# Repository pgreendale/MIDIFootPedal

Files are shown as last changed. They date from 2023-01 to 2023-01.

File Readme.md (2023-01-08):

# MIDI Interface for a organ footpedal
<figure>
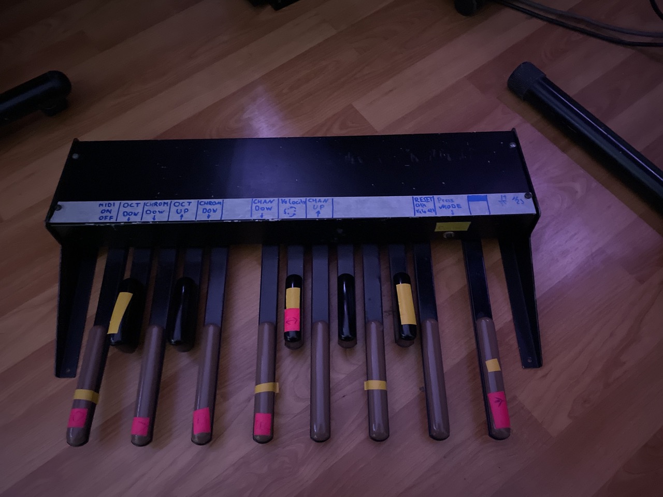
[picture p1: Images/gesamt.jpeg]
Completed pedal
    
    <figcaption>Midified organ pedal.</figcaption>
</figure>
## Intro
This device came from a friend. I assume, its base came from an Vermona ET6-2 organ,
an electronic organ produced in the former GDR. The build is simple, just long hinges with
pull springs and a switch per pedal.

Someone converted it before, but the original interface from unknown origin is dead.

Analysing the circuit revealed switches organized in groups, eight per group, so
multiplexing is possible and there were also diodes installed, which allows polyphonic
muxed readout.

I replaced that interface board with the Arduino nano and kept an eye on using as
few as possible external components (parts shortage, you know?). The AVRs have
useful pullups, so nothing special.

## Features
Polyphonic.
Base Note, Midi Channel and Velocity are configurable.

## Build
<figure>
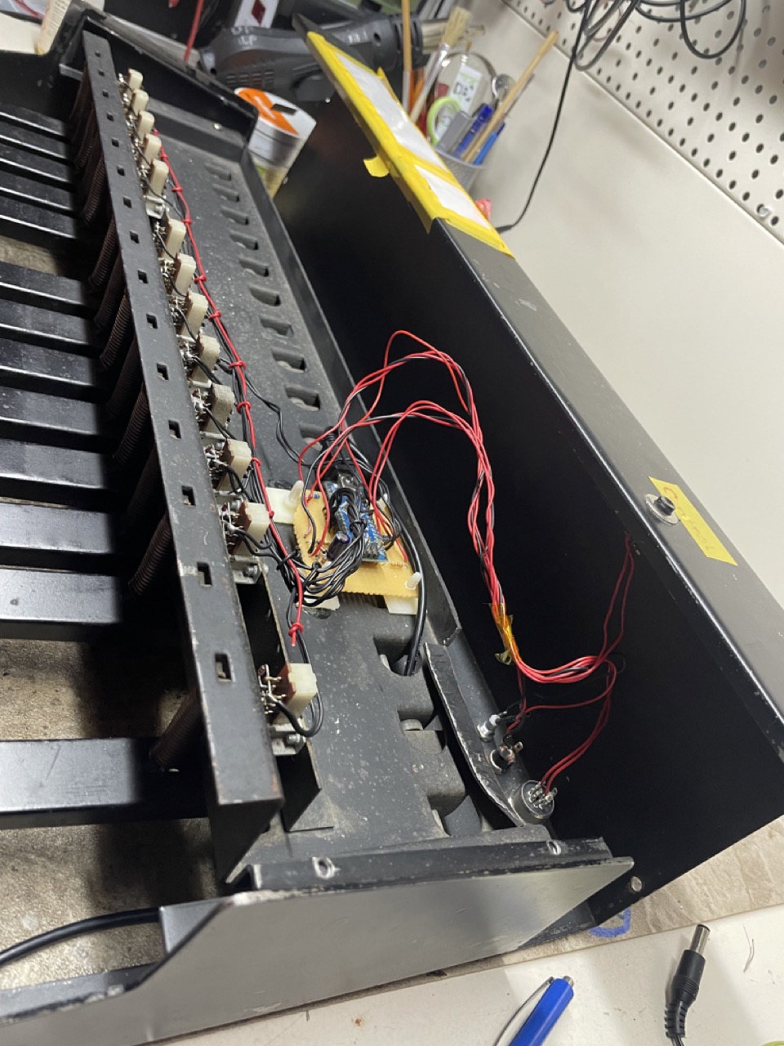
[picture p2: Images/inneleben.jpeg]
Pedals guts, housing removed
    
    <figcaption>A look at the pedals guts reveal the newly installed Arduino and messy wiring</figcaption>
</figure>

### Hardware needed
* Arduino Uno / Nano with Atmega328 
* 2 220k resistors for MIDI
* 5 1k resistors for buttons and LED
* Buttons / momentary switches (! Carbon pad switches may have too much resistance)
Schmatics are [here]().

The build is easy. I put the arduino on perfboard, added the midi resistors and the input filtering/protection, then connected the keys. If you change the design for more
key groups, add a 1k resistor in the added multiplexed lines. This is basic protection
when the MCU in in random condition at powerup.

When build, compile the arduino sketch, upload it and voila! If something doesn't go as expected, you can use the debugging mode for some basic checks.

### Note on powersupplies
For Power regulation, arduino's internal linear regulator is used.
Depending on source, the absolute maximum voltage may be in the 15V ballpark (as
  my arduino clones from [AZ Delivery](https://www.az-delivery.de/products/nano-v3-mit-ch340-arduino-kompatibel) are). If you power those, remember that rectified transformer powersupplies have peaking off-load-voltages which are much higher than the specified RMS (usually by 1.4141 * V_RMS) because of sinusodial RMS to peak values. Since our arduino has low power demands, voltage goes up to nearly off-load.
  I would say, a 9V DC powersupply is safe to use, every kind of switching power supply, Batteries etc.

## Software
The Midi handling is done by the [FourtySevenEffects](https://github.com/FortySevenEffects/arduino_midi_library) library.
It may be a little overkill for sending simple note-on and note-off values, but I liked
the Idea of trying it out, there is a good [Doxygen](https://fortyseveneffects.github.io/arduino_midi_library/) documentation.

The software is customizable, feel free to change PIN numbers for your designs if needed.

There is some pointer magic and some size=sizeof() stuff implemented, to keep the
design expandable, you can add additional key groups by adding pin numers to the
*MUX_PORTS[]* array.

## Debugging
There is a simple debug mode implemented, which is activated if the *mode button* is
held down **during a reset** until the software changes into modeswitch (led is blinking). If you connect a computer via the Arduino USB Interface and open a serial console on the usb serial device with 9600baud transmission rate, you'll see information about the internal eeprom state, which key is pressed, keyboard state
values and if the unit tries to send on or off messages via midi.

Please note that midi operation is not possible in debug mode due to different UART speeds used for midi and debugging.

## Mode button
The mode button allows on-stage configuration of the interface.
On my pedal, it is organized as following:

| Nr. | Key | Function |
|-----|---|---|
| 1 | C_0 | Midi on/off (not implemented) |
| 2 | **C#_0** | Shift Keys 1 Octave down |
| 3 | D_0 | Shift Keys 1 Semitone down |
| 4 | **D#_0** | Shift Keys 1 Octave up |
| 5 | E_0 | Shift Keys 1 Semitone up |
| 6 | F_0 | Change MIDI channel DOWN |
| 7 | **F#_0** | Cycle Velocity by + 1/4 range |
| 8 | G_0 | Change MIDI channel UP |
| 12  | B_0 | **RESET** settings to default |
| 13  | C_1 | Send Midi Panic CC120 on Chan |

To activate the options, press the mode button, the LED changes from static
to blinking, then press the key corresponding to your intended change. The
changes are immediately applied and stored in memory, so everything will
be kept for the net gig. The new midi channel is displayed when changed.

If you have pressed mode by accident, just wait until the LED stops blinking, about 10
seconds.  

Key Functions can be changed, rearranged or removed in Source Code. The Key numbers are absolute, so Key 9 means the first key in the second group.

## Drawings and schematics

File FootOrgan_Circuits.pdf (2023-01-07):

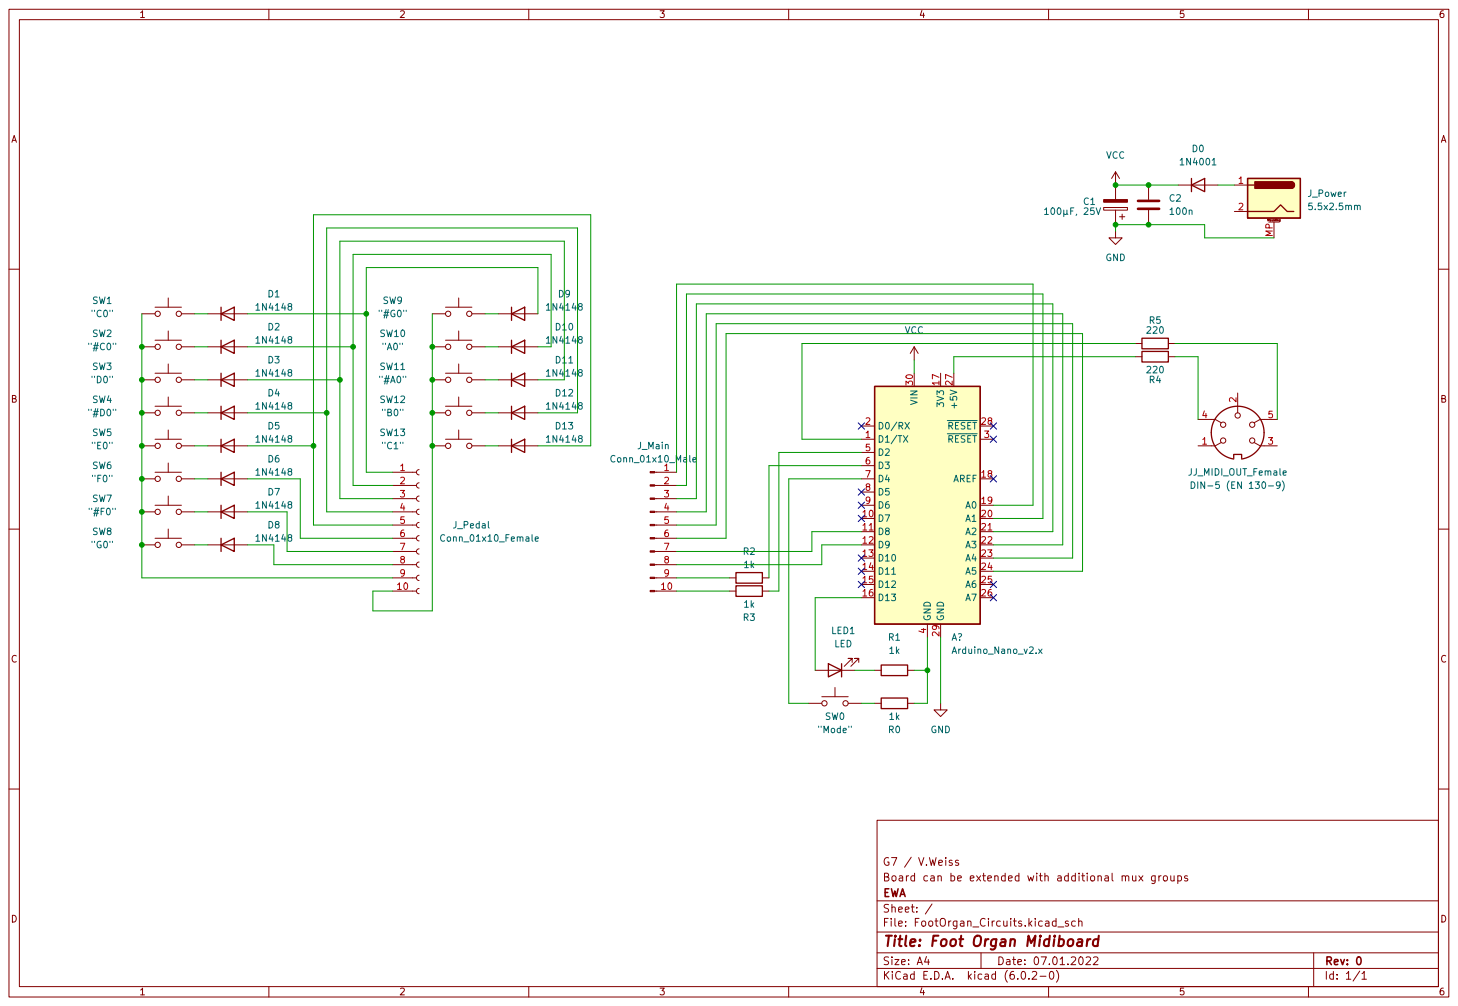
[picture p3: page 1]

Board can be extended with additional mux groups G7 / V.Weiss

Id: 1/1 Title: Foot Organ Midiboard

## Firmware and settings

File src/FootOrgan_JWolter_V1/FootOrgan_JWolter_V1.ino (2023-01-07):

#include <MIDI.h>
#include <EEPROM.h>

int ledPin = 13; 
int modePin = 4;
/* input Switch Configurations */
int SW_KEY[]{
  14,15,16,17,18,19,8,9
};
int SW_LEN = sizeof(SW_KEY)/sizeof(SW_KEY[0]);

/*Pins for muxing inputs*/
int MUX_PORTS[]{
  2,3
};

/*
  Key state variable, 0 = no key pressed , assuming n_mux 
  muxed switch groups with 8 bit port width and 
*/
byte KEY_STATE[sizeof(MUX_PORTS)/sizeof(MUX_PORTS[0])]{0};

struct Config{
  byte velocity; 
  byte note_offset; 
  byte channel;
  bool midi_on;
  byte debug;
};
//configuration struct 
Config conf;

//set true if generic debugging is wanted 
bool debug_mode = false ;

/*mode number definitions MODE_ALIAS Key Number*/
#define MIDI_ON_OFF 1 
#define OCT_UP 4
#define OCT_DOWN 2
#define CHROM_UP 5
#define CHROM_DOWN 3
#define CHAN_UP 8
#define CHAN_DOWN 6
#define VELOCITY 7 
#define RESET_DEFAULT 12 
#define PANIC 13
//timeout cycle in menue, maximum in 100ms steps 
#define TIMEOUT_MAX 100 

MIDI_CREATE_DEFAULT_INSTANCE();

/*
  reads keyboard and returns count of first key found (usually lowest)
*/
void debug(void);
void read_keys(int mux[], byte state[]);


int read_key_single(void){
  read_keys(MUX_PORTS, KEY_STATE); //update keys
  int temp = 0;
  for(int group_idx = 0; group_idx < sizeof(KEY_STATE)/sizeof(KEY_STATE[0]) ; group_idx++ ){ 
    byte mask = 0x01; 
    for(int key_idx = 1; key_idx <= 8 ; key_idx++){
      if((mask & KEY_STATE[group_idx]) != 0) {
          return(group_idx * 8 + key_idx);
        }
        mask = mask << 1 ; 
      }
    }
  return 0;
}
/* Changes configuration by pressing a key according to its second function*/
void modeswitch(){
  int choice  = 0;
  if (debug_mode){
        debug();
  }
  while(digitalRead(modePin)==LOW){
    int timeout = 0; 
    while( (choice==0) && (timeout < TIMEOUT_MAX) ){
      choice = read_key_single();
      if(debug_mode){
        Serial.print("Mode:");Serial.println(choice); 
      }
      digitalWrite(ledPin, HIGH);
      delay(50);
      digitalWrite(ledPin, LOW); 
      delay(50);
      timeout++;
    }
    switch(choice){
      case MIDI_ON_OFF :
        conf.midi_on = ~conf.midi_on; 
        led_blink(ledPin, 1); 
      break;
    
      case OCT_UP:
        if (conf.note_offset < 127 - 12){ 
          conf.note_offset = conf.note_offset + 12; 
        }
        led_blink(ledPin, 1);
        break; 
      case OCT_DOWN: 
        if (conf.note_offset > 12){ 
          conf.note_offset = conf.note_offset - 12; 
        }
        led_blink(ledPin, 1);
        break; 
      case CHROM_UP:
        if (conf.note_offset < 127 ){ 
          conf.note_offset = conf.note_offset + 1; 
        }
        led_blink(ledPin, 1);
        break; 
      case CHROM_DOWN: 
        if (conf.note_offset > 1){ 
          conf.note_offset = conf.note_offset -1 ; 
        }
        led_blink(ledPin, 1);
        break; 
      
      case CHAN_UP: 
        if (conf.channel< 16){
          conf.channel = conf.channel + 1 ;
        }
        led_blink(ledPin, (int)conf.channel); 
        break;
      case CHAN_DOWN:
        if (conf.channel > 1){
          conf.channel = conf.channel -1; 
        }
        led_blink(ledPin, (int)conf.channel); 
        break; 
      
      case VELOCITY:
        conf.velocity = (conf.velocity + 32 ) % 127 ; 
        led_blink(ledPin, (int)conf.velocity / 32); 
        break; 
      case RESET_DEFAULT:
        conf.velocity    = 127;
        conf.note_offset = 60; //middle C as default  
        conf.channel     = 1;
        conf.midi_on     = true;
        conf.debug       = false;
        break;
      case PANIC:
        if(~debug_mode){
          MIDI.sendControlChange(120, 0 , conf.channel);
        }
        break; 
      
      default: 
        break; 
  }
  EEPROM.put(0, conf); 
  
  while(choice != 0){
    //Wait until pressed key is released on keyboard
    digitalWrite(ledPin, HIGH);
    choice = read_key_single(); 
    if(debug_mode){
      Serial.print("Wait for Key:");Serial.println(choice);
    }
    
    
    delay(100); 
  }
  if(debug_mode){
     Serial.println("Mode Exit");
  }
  //wait for mode key to be released
  ;; 
  }
  digitalWrite(ledPin, LOW);
}
void debug(){
  Serial.print("Config.velocity\t\t\t");Serial.println(conf.velocity); 
  Serial.print("Config.note_offset\t\t");Serial.println(conf.note_offset);
  Serial.print("Config.channel\t\t\t");Serial.println(conf.channel);
  Serial.print("Debug midi on \t\t\t");Serial.println(conf.midi_on);
  Serial.print("Debug (eeprom)\t\t\t");Serial.println(conf.debug);  
  Serial.print("\n\n");
}
/*Does nblink short blinks on pin and restores previos port state*/
void led_blink(int pin, int nblink){
  int tmp = digitalRead(pin); 
  for(int i =  1; i <= nblink; i++){
    digitalWrite(pin, LOW); 
    delay(300); 
    digitalWrite(pin, HIGH); 
    delay(200); 
  }
  digitalWrite(pin, tmp);
}
/* configures all pin numbers listed in array as inputs with pullup */
void set_port_input(int arr[]){
  int * ptr = arr;
  while( * ptr != NULL){
    pinMode(*ptr, INPUT_PULLUP);
    ptr++;
  }
}

/* 
  reads input state of pins listed in input array 
  returns byte with state, this limits output to 8 pins
 */
byte read_port(int arr[]){
  int * ptr = arr;
  byte idx = 0;
  byte port_state = 0x00;
  while(*ptr != NULL){
    port_state |= (digitalRead(*ptr) << idx);
    ptr++;
    idx++;
   }
  return ~port_state;  
}

/*
  for each mux_pin in mux[] array, 
  key states will be read and written to referred state array
  mux and state array has to have the same length! 
  low-active because key inputs have pullups to vcc activated
*/ 
void read_keys(int mux[], byte state[]){
  int* mux_ptr = mux;
  byte* state_ptr = state; 
  while (*mux_ptr != NULL){
    pinMode(*mux_ptr, OUTPUT); 
    digitalWrite(*mux_ptr, LOW);
    *state_ptr = read_port(SW_KEY);
    digitalWrite(*mux_ptr, HIGH); 
    pinMode(*mux_ptr, INPUT_PULLUP); //
    mux_ptr++;
    state_ptr++;
  }
}

void setup() { 
  conf = EEPROM.get(0,conf);
  pinMode(ledPin, OUTPUT);
  pinMode(modePin, INPUT_PULLUP);
  delay(100);
  if(digitalRead(modePin)==LOW ){
    Serial.begin(9600);  
    Serial.print("***Debug mode***\n\n");
    debug_mode = true ;
  }else
  { 
    MIDI.begin(MIDI_CHANNEL_OMNI);
  }
   
  pinMode(ledPin, OUTPUT);
  set_port_input(SW_KEY); 
}

void loop() {
  byte state_old [sizeof(KEY_STATE)/sizeof(KEY_STATE[0])] = {0}; 
  byte mask = 0;
  while(1){
    if (digitalRead(modePin)==HIGH){
      /*Midi Loop happens here*/
        read_keys(MUX_PORTS,KEY_STATE);
        for(int i=0 ; i< sizeof(KEY_STATE)/sizeof(KEY_STATE[0]); i++){
          mask = 0x01; 
          byte kdiff_on  =  KEY_STATE[i] & ~state_old[i] ; // only keys which are pressed and not pressed before
          byte kdiff_off = ~KEY_STATE[i] &  state_old[i] ; // only keys which are old but not pressed anymore
          for(int key_idx = 0; key_idx < 8; key_idx++){
            if((mask & kdiff_on) != 0){
              if(debug_mode){
                Serial.print("NoteOn, ");Serial.print(conf.note_offset + 8*i  + key_idx);
                Serial.print(" Velocity:");Serial.print(conf.velocity);Serial.print(" Chan");Serial.println(conf.channel);
              }else{
                MIDI.sendNoteOn( conf.note_offset + 8*i + key_idx , conf.velocity, conf.channel);
              }
            }
            if((mask & kdiff_off) != 0){
              if(debug_mode){
                Serial.print("NoteOff, ");Serial.print(conf.note_offset + 8*i + key_idx);
                Serial.print(" Velocity:");Serial.print(0);Serial.print(" Chan");Serial.println(conf.channel);                
              }else{
                MIDI.sendNoteOff( conf.note_offset + 8*i + key_idx , 0, conf.channel);
              }
            }
              mask = mask << 1 ; //rotate mask for one_hot encoding
            }
          }
        memcpy(state_old, KEY_STATE, sizeof(KEY_STATE));   //copy actual state to old state
        delay(1); //delay 1ms to avoid polling 
    }else{
      modeswitch();
    }
    //add Delay in Debug Mode
    if(debug_mode){
      for(int i=0; i< sizeof(KEY_STATE)/sizeof(KEY_STATE[0]); i++){
        Serial.print("State");Serial.print(i);Serial.print(':');Serial.println(KEY_STATE[i]);
      }
      delay(500);
      digitalWrite(ledPin,1^digitalRead(ledPin));
    }
    delay(1);
    digitalWrite(ledPin,1^digitalRead(ledPin));
  } // end main loop 

}
